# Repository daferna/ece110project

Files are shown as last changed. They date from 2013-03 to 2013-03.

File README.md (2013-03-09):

#ECE110 Lab Final Project

The final design project for the ECE 110 lab involves programming a small car to do line following around a track. You can read more about it [here](http://courses.engr.illinois.edu/ece110/Lab/).

*	The ece110 folder contains an Arduino sketch used for running the robot.
*	The eeprom\_write\_calibrate folder contains an Arduino sketched used for writing calibration values for the IR sensors to the EEPROM.
*	The report.tex can be compiled yourself, or you can read the ready-made report.pdf output.

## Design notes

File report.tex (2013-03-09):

\documentclass{article}

\usepackage{pdfpages}
\usepackage{mathtools}

\author{Daniel Fernandes \and Yue Li}
\title{ECE 110 Final Design Project}
\date{December 6, 2012}

\begin{document}
\maketitle

\part{Introduction}
The final design project involves programming a small, two-motor car to follow a white line around a track using only IR Sensors combined with either TTL Logic or an Arduino microprocessor. We have chosen an Arduino Micro, with a CAB Module (H-Bridge) and Arduino-compatible CA module (BJT Transistor) for each side of the car.
\part{Design}
\section{Hardware Design}
\subsection{Sensors}
Our sensor layout uses two IR sensors (A5 and A6) in the outermost bar to detect splits and for stop detection. When both sensors see the white line, this indicates that we have reached a split. After two splits, we reuse this circuit for stop detection.\\
The second sensor bar, placed closer to the car, uses two IR sensors (A9 and A10) on the outer edges for right turn detection. Five more sensors (A0-A4) are distributed symmetrically about the center axis of the sensor bar. The center sensor (A2) is critical for detecting the color for split detection. The two sensors adjacent from the center (A1 \& A3) are used for the Tape Avoiding / Tape Seeking navigation scheme. The remaining two sensors (A0 \& A4) are used for right turn detection. They were initially placed for a PID loop, but the PID loop was not suited to our needs.
\subsection{CAB}
The CAB module provides a H-Bridge in order to invert motor direction with a single digital output. The key to making the CAB module work is to connect Vmotor and GND for the Vmotor pin to the Motor1 and Motor2 pins of the CA Module. This allows us to control the current through the CAB from the CA.\\
In order to control the polarity of the H-Bridge, we shorted pins T2 and T4 to ground, connected T1 to a digital output pin from the Arduino and used a NOT TTL chip to invert the signal from T1 to T3.
\subsection{CA Module}
The Arduino CA module was straightforward to setup. The Motor1 and Motor2 pins could go directly to the leads for the motor, but we decided to run these through the CAB H-Bridge for more functionality. The ON/OFF pin of the CA Module is connected to a PWM output pin on the Arduino.
\subsection{Arduino}
We initially started with a standard Arduino UNO available from the ECE Store, but we found the Arduino Micro (from AdaFruit Industries) to offer better functionality in a better form factor. The Arduino Micro has all the pins of a Arduino UNO, but uses an smaller SMD (surface mount device) chip rather the DIP (dual in-line package) chip used in the UNO. It also has headers that make it a drop-in solution for a protoboard like the one used in the ECE 110 lab. In fact, the Micro has more analog inputs available than the UNO which was useful for our design.
\subsection{Wiring}
Our wiring used the two innermost power rails to provide 5V to logic chips and the two outermost power rails to provide 12V to the motors. We rewired the board several times, using the shortest wires possible to minimize clutter. IR Sensor inputs were routed out from the Arduino to the front of the vehicle, making the setup of the analog sensor bar a less arduous task.
\includepdf[angle=90]{ece110sketch_schem.pdf}
\includepdf{ece110drawings.pdf}
\section{Software Design}
\subsection{Calibration Code}
Rather than using a comparator circuit, we took advantage of the Arduino Micro's massive 1KB EEPROM storage to store sensor values. These sampled values were used to computed a "white threshold" and "black threshold". The white threshold being the lowest value before a sensor could be declared white, and the black threshold indicating the highest value a sensor value could hold before it could no longer be declared black. Grey is between the black and white thresholds. To do this, we created a separate calibration program that asks the user over serial input what sensor is being calibrated and for what color (white or black). The program will print out the current values that sensor is reading and will save the last value received into the EEPROM once the user presses 'k'. The threshold values were computed using the following formulas:
\begin{align}
midpoint = \frac{whiteSample + blackSample}{2}\\
whiteThreshold = \frac{midpoint + whiteSample}{2}\\
blackThreshold = \frac{midpoint + blackSample}{2}
\end{align}
\subsection{PID Loop}
Initially, we tried using a PID Loop (Proportional-Integral-Derivative), but this did not pan out for several reasons. In a nutshell, the PID Loop is a type of feedback loop used that takes an input of error and outputs power to correct the error. The ``Proportional" part of the loop responds to immediate error, the ``Integral" part responds to past error, and the ``Derivative" part responds to future error. The PID Loop requires careful analysis to avoid problems such as ``Integral Windup" where too much error has been accumulated for too long and the output becomes too skewed. Another problem was trying to determine a numerical value for the error distribution. An effort was made towards this in the \textit{errorScore()} function but the benefits of such a complex system were not enough to justify the time investment for the limited lab sessions available.
\subsection{Tape Avoider / Tape Seeking Hybrid}
Once the PID plan had been abandoned, we chose one of the navigation schematics introduced in previous labs. This is essentially a Tape Avoiding circuit, except one side of the car always has a bit more power than the other. This forces the car to drive into the white line and recorrect itself. This gives the speed benefits of a Tape Avoiding circuit, with the accuracy advantages of a Tape Seeking circuit. This ended up being the design we chose for the final trial and it preformed exceptionally well. 
\subsection{Right Angle Turn Detection}
For right angle turn detection we test if a outermost sensor on the second sensor bar sees white (Sensors A9 \& A10), and another inner sensor on the same side sees white. The reason we need a second sensor is to ensure that we are actually at right turn and not crossing a split. For example, when the car turns right on a Y, the leftmost sensor would see white for a moment, which would incorrectly trigger the turning code.\\
Once we detect a turn, we drive forward a little bit, and start turning until the center sensor sees the line again.
\subsection{Split Detection}
The split detection occurs when the two frontmost sensors see white (Sensors A5 \& A6). The sensors are placed such that they trigger right when the centermost sensor (A2) is in an optimal position to read the color of the split. We use the color calibration mentioned previously to read if the center sensor sees grey or white. We act on this information by supplying turning power in the corresponding direction.
\subsection{Stop Detection}
After incurring two splits, we reuse the split detection sensors for stop detection and cut power to the motors.
\includepdf[page=2]{ece110drawings.pdf}
\part{Design Philosophy}
Our design process started with the choice to use the Arduino microcontroller, rather than TTL logic. Using a microprocessor allows the design to use the same IR sensors for triggering different reactions. Many TTL logic designs have IR sensors dedicated to one task---such as split detection or stop detection. A microprocessor can address each IR sensor individually and use the same sensors for split detection and stop detection.\\
Additionally we put numerous debugging statements in the code that will printout the current state of the robot over the Arduino's USB interface. By reading this data, we were able to isolate and solve both hardware and software issues.
\part{Performance}
Our tape seeking / tape avoiding hybrid preformed excellently on the straight, curvy, and zig-zag parts of the track. The right turn detection circuit preformed much better than expected, the car would drive into the turn, backup and run into the turn again at a steeper angle, repeating the process until completed. Our split detection software successfully detected the first grey split, but incorrectly interpreted a white split, and went left. This was because our sensor bar was too close to the table, making grey and white indistinguishable. After moving the sensor bar up, we recalibrated all the sensors and showed the split detection correctly detected the color of the split, but the battery was too low and the time too little to try another attempt. We did not get to the point where we tested the stop detection. In the end we earned 35/40 points.

\part{Future Improvements}
In the future, we would like to add an LCD display to improve debugging efficiency. We would also add another IR sensor to the outermost sensor bar, in the centermost position for stop detection. Rather than counting the number of splits, which can be inaccurate, we can simply stop the car if all three sensors on the outermost bar return white. A true split would only trigger the two outermost sensors. For software, we would like to fully implement the PID loop.
\end{document}

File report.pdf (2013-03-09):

# ECE 110 Final Design Project

Daniel Fernandes | Yue Li

December 6, 2012

## Part I

# Introduction

The final design project involves programming a small, two-motor car to follow a white line around a track using only IR Sensors combined with either TTL Logic or an Arduino microprocessor. We have chosen an Arduino Micro, with a CAB Module (H-Bridge) and Arduino-compatible CA module (BJT Transistor) for each side of the car.

## Part II

# Design

## 1 Hardware Design

### 1.1 Sensors

Our sensor layout uses two IR sensors (A5 and A6) in the outermost bar to detect splits and for stop detection. When both sensors see the white line, this indicates that we have reached a split. After two splits, we reuse this circuit for stop detection.
The second sensor bar, placed closer to the car, uses two IR sensors (A9 and A10) on the outer edges for right turn detection. Five more sensors (A0-A4) are distributed symmetrically about the center axis of the sensor bar. The center sensor (A2) is critical for detecting the color for split detection. The two sensors adjacent from the center (A1 & A3) are used for the Tape Avoiding / Tape Seeking navigation scheme. The remaining two sensors (A0 & A4) are used for right turn detection. They were initially placed for a PID loop, but the PID loop was not suited to our needs.

1

### 1.2 CAB

The CAB module provides a H-Bridge in order to invert motor direction with a single digital output. The key to making the CAB module work is to connect Vmotor and GND for the Vmotor pin to the Motor1 and Motor2 pins of the CA Module. This allows us to control the current through the CAB from the CA.
In order to control the polarity of the H-Bridge, we shorted pins T2 and T4 to ground, connected T1 to a digital output pin from the Arduino and used a NOT TTL chip to invert the signal from T1 to T3.

### 1.3 CA Module

The Arduino CA module was straightforward to setup. The Motor1 and Motor2 pins could go directly to the leads for the motor, but we decided to run these through the CAB H-Bridge for more functionality. The ON/OFF pin of the CA Module is connected to a PWM output pin on the Arduino.

### 1.4 Arduino

We initially started with a standard Arduino UNO available from the ECE Store, but we found the Arduino Micro (from AdaFruit Industries) to offer better functionality in a better form factor. The Arduino Micro has all the pins of a Arduino UNO, but uses an smaller SMD (surface mount device) chip rather the DIP (dual in-line package) chip used in the UNO. It also has headers that make it a drop-in solution for a protoboard like the one used in the ECE 110 lab. In fact, the Micro has more analog inputs available than the UNO which was useful for our design.

### 1.5 Wiring

Our wiring used the two innermost power rails to provide 5V to logic chips and the two outermost power rails to provide 12V to the motors. We rewired the board several times, using the shortest wires possible to minimize clutter. IR Sensor inputs were routed out from the Arduino to the front of the vehicle, making the setup of the analog sensor bar a less arduous task.

2

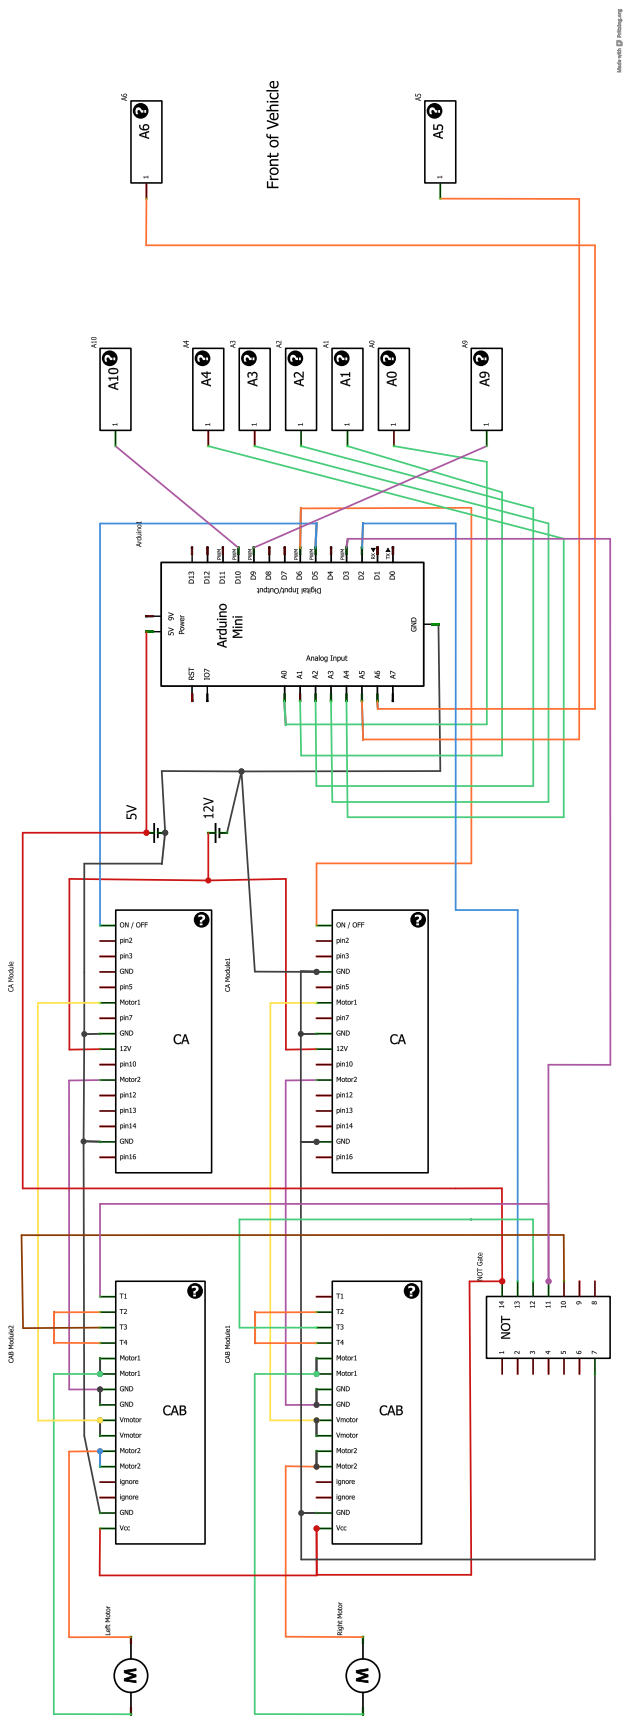
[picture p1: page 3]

# CAR

## A6 X X X X X X X X X X X X X X X X X A5

## A10 X X X X A4 X A3 X A2 X A1 X A0 X X X X A9

1
2
3
4
5
6
CA | CA
CAB | CAB

# ARDUINO

## 2 Software Design

### 2.1 Calibration Code

Rather than using a comparator circuit, we took advantage of the Arduino Micro’s massive 1KB EEPROM storage to store sensor values. These sampled values were used to computed a ”white threshold” and ”black threshold”. The white threshold being the lowest value before a sensor could be declared white, and the black threshold indicating the highest value a sensor value could hold before it could no longer be declared black. Grey is between the black and white thresholds. To do this, we created a separate calibration program that asks the user over serial input what sensor is being calibrated and for what color (white or black). The program will print out the current values that sensor is reading and will save the last value received into the EEPROM once the user presses ’k’. The threshold values were computed using the following formulas:

midpoint =

whiteSample + blackSample
2

(1)

whiteT hreshold =

midpoint + whiteSample
2

(2)

blackT hreshold =

midpoint + blackSample
2

(3)

### 2.2 PID Loop

Initially, we tried using a PID Loop (Proportional-Integral-Derivative), but this did not pan out for several reasons. In a nutshell, the PID Loop is a type of feedback loop used that takes an input of error and outputs power to correct the error. The “Proportional” part of the loop responds to immediate error, the “Integral” part responds to past error, and the “Derivative” part responds to future error. The PID Loop requires careful analysis to avoid problems such as “Integral Windup” where too much error has been accumulated for too long and the output becomes too skewed. Another problem was trying to determine a numerical value for the error distribution. An effort was made towards this in the errorScore() function but the benefits of such a complex system were not enough to justify the time investment for the limited lab sessions available.

### 2.3 Tape Avoider / Tape Seeking Hybrid

Once the PID plan had been abandoned, we chose one of the navigation schematics introduced in previous labs. This is essentially a Tape Avoiding circuit, except one side of the car always has a bit more power than the other. This forces the car to drive into the white line and recorrect itself. This gives the speed benefits of a Tape Avoiding circuit, with the accuracy advantages of a Tape Seeking circuit. This ended up being the design we chose for the final trial and it preformed exceptionally well.

5

### 2.4 Right Angle Turn Detection

For right angle turn detection we test if a outermost sensor on the second sensor bar sees white (Sensors A9 & A10), and another inner sensor on the same side sees white. The reason we need a second sensor is to ensure that we are actually at right turn and not crossing a split. For example, when the car turns right on a Y, the leftmost sensor would see white for a moment, which would incorrectly trigger the turning code.
Once we detect a turn, we drive forward a little bit, and start turning until the center sensor sees the line again.

### 2.5 Split Detection

The split detection occurs when the two frontmost sensors see white (Sensors A5 & A6). The sensors are placed such that they trigger right when the centermost sensor (A2) is in an optimal position to read the color of the split. We use the color calibration mentioned previously to read if the center sensor sees grey or white. We act on this information by supplying turning power in the corresponding direction.

### 2.6 Stop Detection

After incurring two splits, we reuse the split detection sensors for stop detection and cut power to the motors.

6

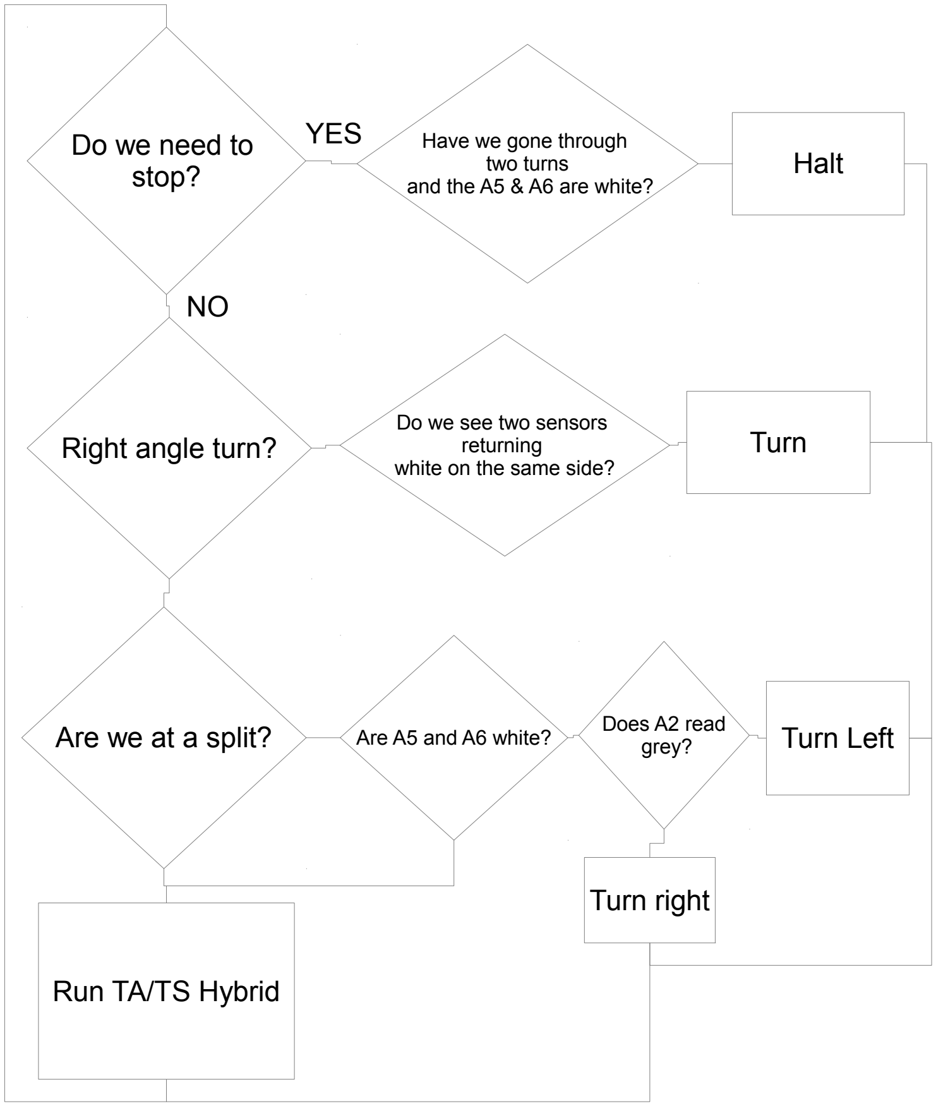
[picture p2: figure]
Do we need to stop?; Right angle turn?; Are we at a split?; Run TA/TS Hybrid; Have we gone through two turns and the A5 & A6 are white?; Halt; Do we see two sensors returning white on the same side?; Turn; Are A5 and A6 white?; Does A2 read; grey?; Turn Left; Turn right; YES

## Part III

# Design Philosophy

Our design process started with the choice to use the Arduino microcontroller, rather than TTL logic. Using a microprocessor allows the design to use the same IR sensors for triggering different reactions. Many TTL logic designs have IR sensors dedicated to one task—such as split detection or stop detection. A microprocessor can address each IR sensor individually and use the same sensors for split detection and stop detection.
Additionally we put numerous debugging statements in the code that will printout the current state of the robot over the Arduino’s USB interface. By reading this data, we were able to isolate and solve both hardware and software issues.

## Part IV

# Performance

Our tape seeking / tape avoiding hybrid preformed excellently on the straight, curvy, and zig-zag parts of the track. The right turn detection circuit preformed much better than expected, the car would drive into the turn, backup and run into the turn again at a steeper angle, repeating the process until completed. Our split detection software successfully detected the first grey split, but incorrectly interpreted a white split, and went left. This was because our sensor bar was too close to the table, making grey and white indistinguishable. After moving the sensor bar up, we recalibrated all the sensors and showed the split detection correctly detected the color of the split, but the battery was too low and the time too little to try another attempt. We did not get to the point where we tested the stop detection. In the end we earned 35/40 points.

## Part V

# Future Improvements

In the future, we would like to add an LCD display to improve debugging efficiency. We would also add another IR sensor to the outermost sensor bar, in the centermost position for stop detection. Rather than counting the number of splits, which can be inaccurate, we can simply stop the car if all three sensors on the outermost bar return white. A true split would only trigger the two outermost sensors. For software, we would like to fully implement the PID loop.

8

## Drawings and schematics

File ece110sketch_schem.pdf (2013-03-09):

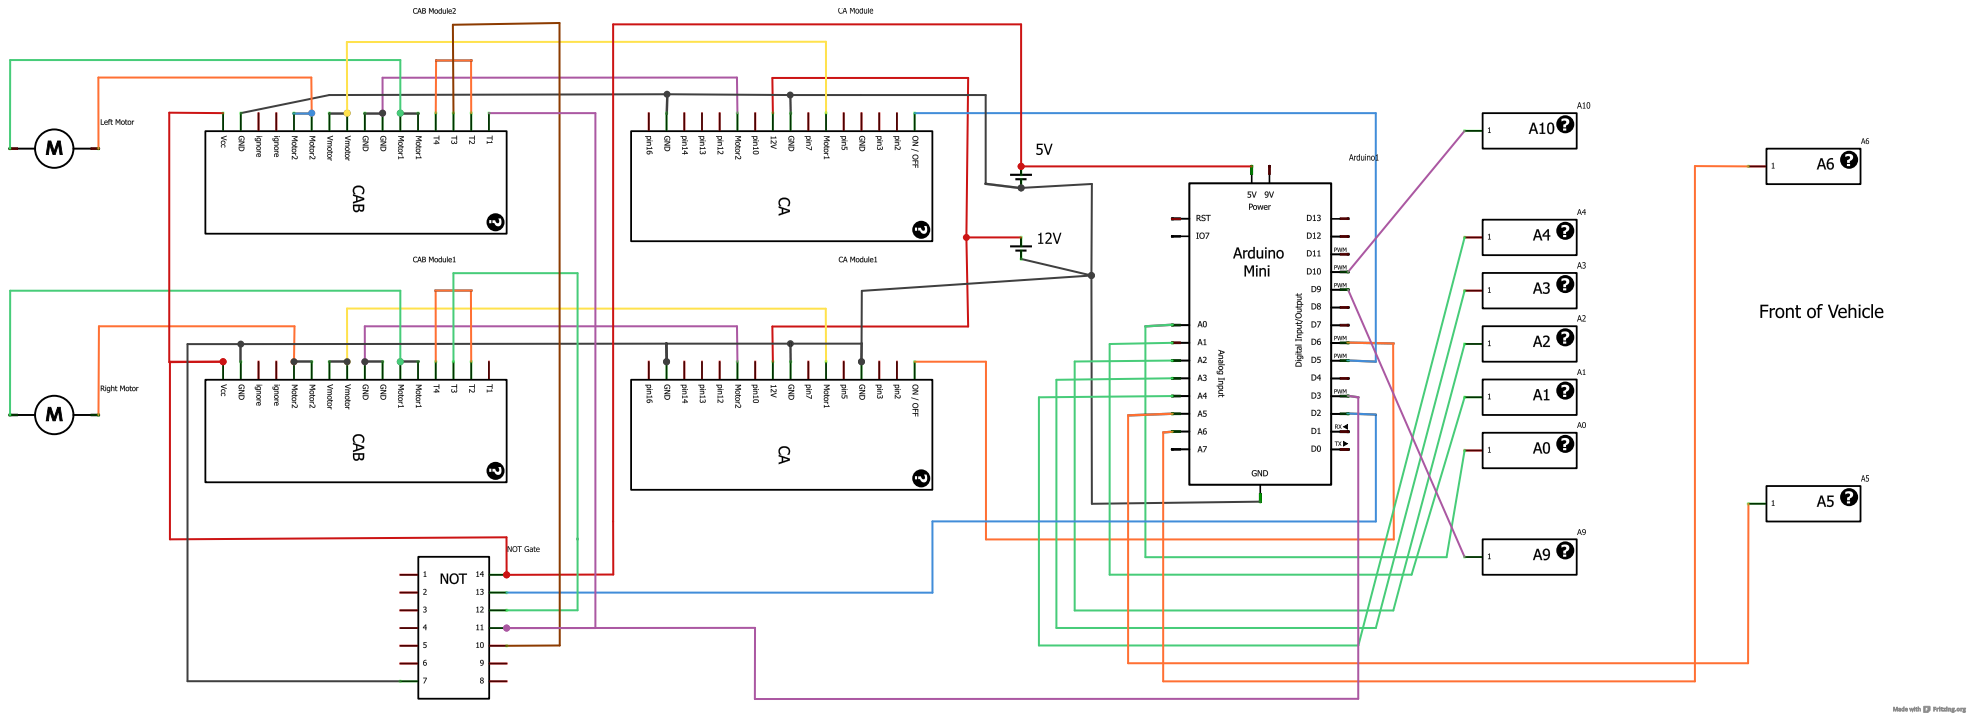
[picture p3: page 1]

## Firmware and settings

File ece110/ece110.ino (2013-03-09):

#include <EEPROM.h>
#include <PID_v1.h>
#include <avr/eeprom.h>

//TODO: Get rid of motor macros, since motor control should only be in loop()

//Port Declarations
int leftMotor = 5;
int rightMotor = 6;
int hBridgeRight = 2;
int hBridgeLeft = 3;
int ledGreySplit = 11;
int ledWhiteSplit = 12;

//Sensor Declarations
byte sensorPin[] = {A0,A1,A2,A3,A4};

//String Declarations

//Constants Declarations
enum robotOp { normal, CW, CCW, halt };
robotOp state = normal;
int timeCount = 0;
int splits = 0;

enum side {left, right};
side powerSide = left;

void setup() {
  //Initialize sensors and motors
  pinMode(leftMotor,OUTPUT);
  pinMode(rightMotor,OUTPUT);
  pinMode(hBridgeRight,OUTPUT);
  pinMode(hBridgeLeft,OUTPUT);
  for(int i=0; i<(sizeof(sensorPin)/sizeof(byte)); i++){ //TODO: check that this works
    pinMode(sensorPin[i],INPUT);
  }
  //We delcare the two outer IR sensors seperately, as an indication that they will not be in the sensor[] array
  pinMode(A9, INPUT); pinMode(A10, INPUT);
  pinMode(A5, INPUT); pinMode(A6, INPUT);
  
  //Set motors to zero initially
  analogWrite(leftMotor,0); analogWrite(rightMotor,0);
  
  //Setup LEDS
  pinMode(ledGreySplit,OUTPUT);
  pinMode(ledWhiteSplit,OUTPUT);
  
  Serial.begin(9600);
}

void loop() {
  /*analogWrite(leftMotor,255);
  analogWrite(rightMotor,255); 
  digitalWrite(hBridgeLeft,HIGH);
  digitalWrite(hBridgeRight,HIGH);
  return;*/
  
  //test for stop
  if(stopTest()){ //Returns True if we need to stop
    analogWrite(leftMotor,0);
    analogWrite(rightMotor,0);
    //state = halt;
    return;
  } 
  
  if(analogRead(A2) > getWhite(A2) && state != normal){
        powerLeft(0); powerRight(0);
        state = normal;
        Serial.println("normal State Set");
  }
  switch(state){
    case CW:
        powerLeft(-50); powerRight(50);
        return;
    break;
    case CCW:
        powerLeft(50); powerRight(-50);
        return;
    break;
  }
  
  //test for sharp turn
  //if A9 and A0-3 lights up we need to right, if A10 and A4-1 lights up, we need to turn left
  if((analogRead(A9) > getWhite(A9)) && (analogRead(A0) > getWhite(A0)|| analogRead(A1) > getWhite(A1)|| analogRead(A2) > getWhite(A2)||analogRead(A3) > getWhite(A3))){
    state = CCW;
    Serial.println("CCW State Set");
    powerLeft(80); powerRight(80);
    delay(250);
  }
  if((analogRead(A10) > getWhite(A10))&& (analogRead(A4) > getWhite(A4)|| analogRead(A3) > getWhite(A3)|| analogRead(A2) > getWhite(A2)||analogRead(A1) > getWhite(A1))){
    state = CW;
    Serial.println("CW State Set");
    powerLeft(80); powerRight(80);
    delay(250);
  }
  
  //test for split
  if(analogRead(A5) > getWhite(A5) && analogRead(A6) > getWhite(A6)){ //If we see white on the two outer sensors
      powerLeft(0); powerLeft(0);
      delay(1000);
      splits++;
    if(analogRead(A2) < getWhite(A2)){ //If we see grey
      digitalWrite(ledGreySplit,HIGH);
      Serial.println("We see a grey split!");
      powerLeft(200); powerRight(0); //TODO: adjust these values
      delay(400);
      digitalWrite(ledGreySplit,LOW);
    } else {
      digitalWrite(ledWhiteSplit,HIGH);
      Serial.println("We see a white split!");
      powerLeft(0); powerRight(200); //TODO: adjust these values
      delay(400);
      digitalWrite(ledWhiteSplit,LOW);
    }
  }

  /* //Tape Follower
  if(analogRead(A1) < getBlack(A1)){
      powerLeft(100); powerRight(200);
  }else if (analogRead(A3) < getBlack(A3)){
      powerLeft(200); powerRight(100);
  } else {
    powerLeft(200); powerRight(200);
  }*/
  
  //Tape Seeking & tape avoiding hybrid
  if(analogRead(A1) > getWhite(A1)){ //If right side of the car see the white tape...
     powerSide = left; //Power the other side
     Serial.println("Left");
  } else if (analogRead(A3) > getWhite(A3)){ //Same for the other side
     powerSide = right;
     Serial.println("Rgiht");
  }
  
  switch(powerSide){
    case left:
      powerLeft(100); powerRight(0); //TODO: adjust these values
      break;
    case right:
      powerLeft(0); powerRight(100); //TODO: adjust these values
    break;
  }
  
  timeCount++;
  if(timeCount >= 1000){
    timeCount = 0;
    for(int i = 0; i < sizeof(sensorPin)/sizeof(byte); i++){
      Serial.print(analogRead(sensorPin[i]));
      Serial.print(" ");
    }
    Serial.print("\n");
    switch (state){
      //enum robotOp { normal, CW, CCW, halt };
      case normal:
        Serial.println("We are normal");
      break;
      case CW:
        Serial.println("We are clockwise");
      break;
      case CCW:
        Serial.println("We are counterclockwise");
      break;
      case halt:
        Serial.println("We are halted");
      break;
    }
    Serial.println("Error score is:");
    Serial.println(errorScore());
  }
}

//Tests
int getBlack(int pin){
  if(pin < 18 || pin > (18 + 11)-1) {
    return -1;
  }
  word blackWord = eeprom_read_word((uint16_t *) ((pin-18)*2));
  word whiteWord = eeprom_read_word((uint16_t *) ((pin-18)*2 + 200));
  word midWord = (blackWord + whiteWord)/2; //TODO: Check that no overflow happens here
  word baseline = (blackWord + midWord)/2;
  return ((int) baseline);
}

int getWhite(int pin){
  if(pin < 18 || pin > (18 + 11)-1) {
    return -1;
  }
  word blackWord = eeprom_read_word((uint16_t *) ((pin-18)*2));
  word whiteWord = eeprom_read_word((uint16_t *) ((pin-18)*2 + 200));
  word midWord = (blackWord + whiteWord)/2; //TODO: Check that no overflow happens here
  word baseline = (whiteWord + midWord)/2;
  return ((int) baseline);
}

boolean stopTest(){
  if(splits >= 2 && (analogRead(A5) > getWhite(A5) && analogRead(A6) > getWhite(A6) && analogRead(A9) > getWhite(A9) && analogRead(A10) > getWhite(A10)))
    return true;
  return false;
}

int errorScore(){
  int winner = 0;
  int winnerVal = 0;
  for(int i = 0; i < sizeof(sensorPin)/sizeof(byte); i++){
    int tempVal = analogRead(sensorPin[i]);
    if(tempVal > winnerVal){
      winner = i;
      winnerVal = tempVal;
    }
  }
  //TODO: Contemplate this
  if(winnerVal < getWhite(sensorPin[winner])){
    return 0;
  }
  switch(winner){
    case 0: 
     return -2;
    case 1:
      return -1;
    case 2:
      return 0;
    case 3:
      return 1;
    case 4:
      return 2;
  }
  return 0;
}

byte turn(int sensor[]){
  boolean firstThreeOn = true;
  for(int i=0; i < 3 && firstThreeOn; i++){
    if(sensor[i]< getWhite(sensorPin[i])){
      firstThreeOn=false;
    }
  }
  if(firstThreeOn)
    return 1;
  
  boolean lastThreeOn = true;
  for(int i=0; i < 3 && lastThreeOn; i++){
    if(sensor[i]< getWhite(sensorPin[i])){
      lastThreeOn=false;
    }
  }
  if(lastThreeOn)
    return -1;
  
  return 0;
}

//Motor macros
void turnCCW(int power){
  if(power > 0){
    digitalWrite(hBridgeLeft,HIGH);
    digitalWrite(hBridgeRight,LOW);
  } else if (power < 0){
    digitalWrite(hBridgeLeft,HIGH);
    digitalWrite(hBridgeRight,LOW);
  }
   analogWrite(rightMotor, power); analogWrite(leftMotor, power);
   return;
}

void powerLeft(int power){
    if (power > 0){
      digitalWrite(hBridgeLeft,HIGH);
    } else if ( power < 0){
      digitalWrite(hBridgeLeft,LOW);
    }
    analogWrite(leftMotor,power);
}

void powerRight(int power){
    if (power > 0){
      digitalWrite(hBridgeRight,HIGH);
    } else if (power < 0){
      digitalWrite(hBridgeRight,LOW);
    }
    analogWrite(rightMotor,power);
}

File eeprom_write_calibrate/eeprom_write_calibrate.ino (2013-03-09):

/*
 * EEPROM Write
 *
 * Stores values read from analog input 0 into the EEPROM.
 * These values will stay in the EEPROM when the board is
 * turned off and may be retrieved later by another sketch.
 */

#include <EEPROM.h>
#include <avr/eeprom.h>

// the current address in the EEPROM (i.e. which byte
// we're going to write to next)
int addr = 0;
//TODO: fix this
byte sensorPin[] = {A0,A1,A2,A3,A4,A9,A10};
int sensorIndex = 0;
enum configState { prompt, pinNum, colorVal, printOutVal, writeOutVal };
enum color {black, grey, white};
configState state = prompt;
color colorState;
void setup()
{
  for(int i = 0; i < (sizeof(sensorPin)/sizeof(byte)); i++){
    pinMode(sensorPin[i], INPUT);
  }
  Serial.begin(9600);
  delay(2000);
}

void loop()
{
  switch(state){
    case prompt:
      Serial.flush();
      Serial.println("What sensor index?");
      state = pinNum;
    break;
    
    case pinNum:
      if(Serial.available() > 0){
        sensorIndex = Serial.parseInt();
        Serial.flush();
        Serial.println("What are we calibrating for? (b,g,w)");
        state = colorVal;
      }
    break;
    
    case colorVal:
      if(Serial.available() > 0){
        byte colorLetter = Serial.read();
        switch(colorLetter){
          case 'b':
            colorState = black;
          break;
          
          case 'g':
            colorState = grey;
          break;
          
          case 'w':
            colorState = white;
          break;
        }
        Serial.flush();
        state = printOutVal;
        Serial.println("Your Color is");
        Serial.println((int) colorState);
        Serial.println("and your pin is");
        Serial.println(sensorIndex);
      }
    break;
      
    case printOutVal:
      word value = analogRead(sensorIndex+18);
      Serial.println(value);
      //If we recieve 'k', write the value out
      if(Serial.available()>0){
        byte incomingByte;
        incomingByte = Serial.read();
        if(incomingByte == 'k'){
          //Alright, we are now ready to store the sensor value
          switch(colorState){
            case black:
              eeprom_write_word((uint16_t*) (2*sensorIndex),value);
              break;
            case grey:
              eeprom_write_word((uint16_t*) ((2*sensorIndex)+100),value);
              break;
            case white:
              eeprom_write_word((uint16_t*) ((2*sensorIndex)+200),value);
              break;
          }
          Serial.println("The Value Stored was");
          Serial.println(value);
          Serial.println("At Location:");
          Serial.println((2*sensorIndex)+200);
          Serial.read();
          state = prompt;
        } 
      }
     break;
  }
  delay(100);
  return;
  // need to divide by 4 because analog inputs range from
  // 0 to 1023 and each byte of the EEPROM can only hold a
  // value from 0 to 255.
  int val = analogRead(0) / 4;
  
  // write the value to the appropriate byte of the EEPROM.
  // these values will remain there when the board is
  // turned off.
  EEPROM.write(addr, val);
  
  // advance to the next address.  there are 512 bytes in 
  // the EEPROM, so go back to 0 when we hit 512.
  addr = addr + 1;
  if (addr == 512)
    addr = 0;
  
  delay(100);
}
